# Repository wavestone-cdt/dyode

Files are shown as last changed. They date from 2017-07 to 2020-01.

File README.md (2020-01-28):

# DYODE : Do Your Own Diode

A DIY, low-cost data diode for ICS
This project aims at creating a working data diode for a fraction of the price of the commercial ones.

This project includes two versions of DYODE :
* DYODE full : a 19" rack-sized data diode

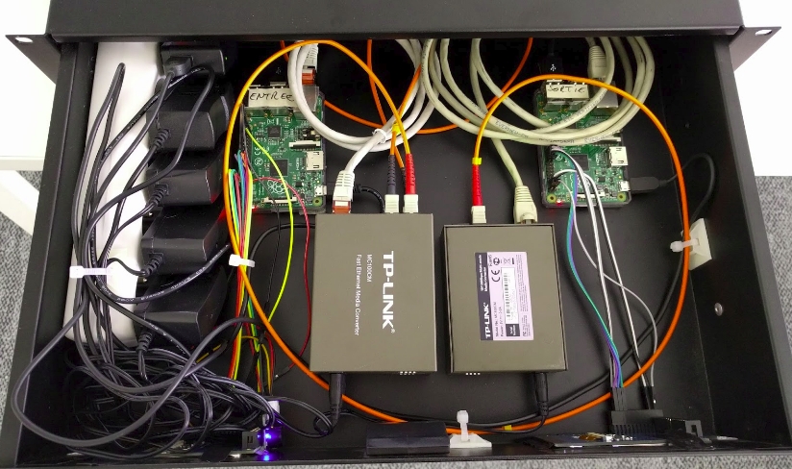
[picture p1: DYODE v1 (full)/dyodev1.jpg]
dyodev1 picture

* DYODE light : a very compact and ultra low-cost version with performance limitations

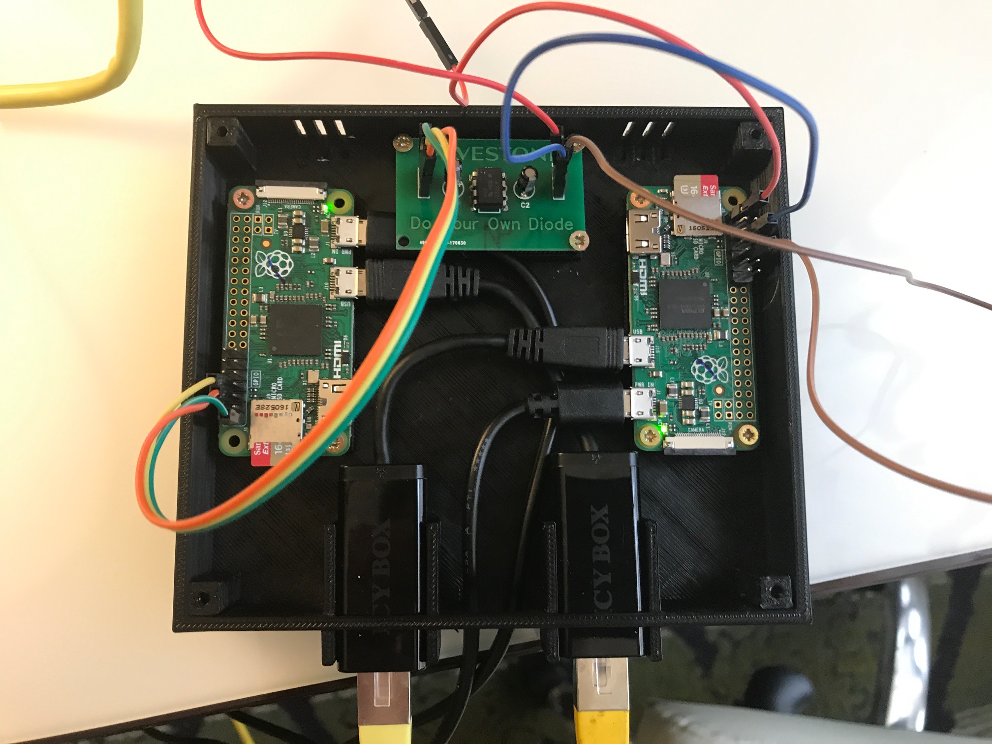
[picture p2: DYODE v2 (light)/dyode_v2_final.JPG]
dyodev2 picture


For detailed information, including steps to make your own, take a look at the [wiki](https://github.com/wavestone-cdt/dyode/wiki).
You may also take a look at the [public talks](https://github.com/wavestone-cdt/dyode/tree/master/Talks) done on this project.

## Hardware
The DYODE project is composed of 3 main parts:
* An INPUT counter
* A unidirectional, light-based data transfer mechanism
* An OUTPUT counter

The full version relies on optical-copper converters to transmit data, while the light version uses an optocoupler.

Hardware for DYODE light is open-source: PCB Gerber files are provided, as well as `.stl` files to 3D print the case.

## Software
DYODE is an open-source project developed in Python.

Features
* Modbus data transfer
* File transfer (*DYODE full only*)
* Screen sharing (*DYODE full only*)

## License
This project is published under GPLv3.
Take a look at [the full license](LICENSE).

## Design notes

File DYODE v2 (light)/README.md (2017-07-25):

# DYODE : Do Your Own Diode

A DIY, low-cost data diode for ICS

dyodev2 picture

This project aims at creating a working data diode for a fraction of the price of the commercial ones.

This is the newest version, using an optocoupler to transmit information.

Please take a look at the [wiki](https://github.com/wavestone-cdt/dyode/wiki) for all information.

## License
This project is published under GPLv3.
Take a look at [the full license](LICENSE).

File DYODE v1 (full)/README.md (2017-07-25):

# DYODE : Do Your Own DyodE
A low-cost (~200 €) data diode aimed at Industrial Control Systems.

## Hardware
We use very standard hardware:
* 3 Copper-Optical converters
* 2 Raspberry Pis
* A few additional components, such as USB-Ethernet NICs, RJ45 cables, ...

## Software
We use ``udpcast`` to transfer files over a unidirectional channel. Modbsu and screen sharing work over a very simple Python UDP socket implementation.

## Features
At the moment, DYODE can be used for the following usages:
* File transfer
* Modbus data transfer
* Screen sharing

You can take a look at the video to learn more about the usage, and ``INSTALL.md`` for installation guidelines.

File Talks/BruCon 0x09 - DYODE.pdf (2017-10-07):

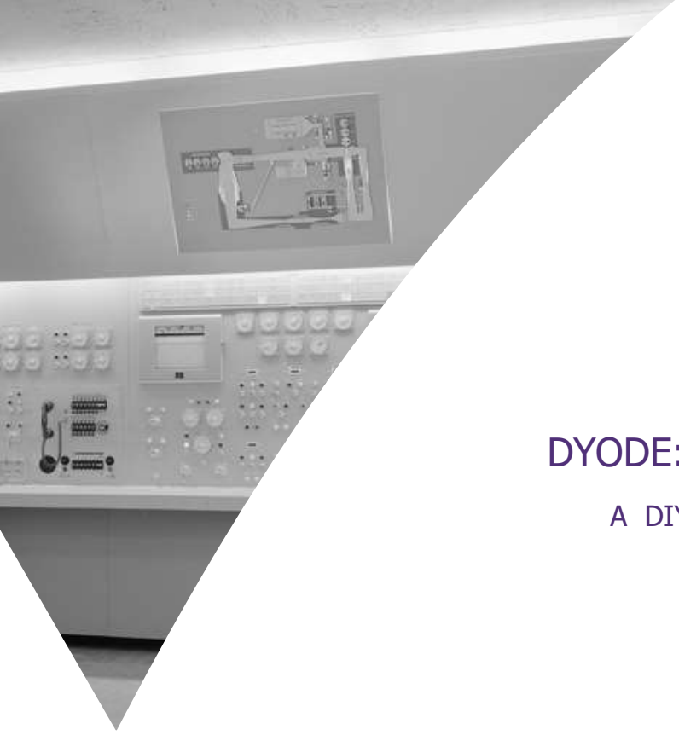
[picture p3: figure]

# DYODE: Do Your Own DiodE

### A DIY, low-cost data diode for ICS

BruCon, October 2017
Arnaud Soullié

UNPROTECTED // PUBLIC CONFERENCE | 2

### Who are we?

DYODE: DO YOUR OWN DIODE

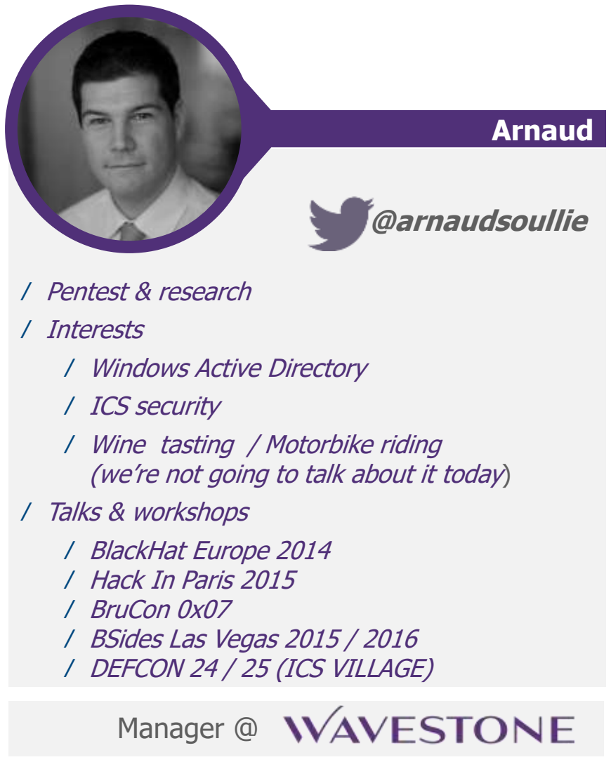
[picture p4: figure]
Manager @; ⁄ Pentest & research; ⁄ Interests; ⁄ Windows Active Directory; ⁄ ICS security; ⁄ Wine tasting / Motorbike riding; ⁄ Talks & workshops; ⁄ BlackHat Europe 2014 ⁄ Hack In Paris 2015 ⁄ BruCon 0x07 ⁄ BSides Las Vegas 2015 / 2016 ⁄ DEFCON 24 / 25 (ICS VILLAGE); Arnaud; @arnaudsoullie

(we’re not going to talk about it today)

⁄ Advisory & audit (used to do pentests) ⁄ Interests
⁄ Windows Security
⁄ Cryptophony

⁄ Talks: IEEE ICC 2009, JSSI 2013 and 2014, SSTIC 2016, Bsides Las Vegas 2016

⁄ Book Information Security, Eyrolles Edition [in French] – written with several authors including Arnaud

Ary

Tax exile @ $Big4 in Switzerland ;)

### ICS 101

### DATA DIODES 101

## / AKA “one-way gateway”

## / Use of light as the transport medium

## / PN junction prevents electrons from going backwards

→ Security property is backed by physics. Hack that.

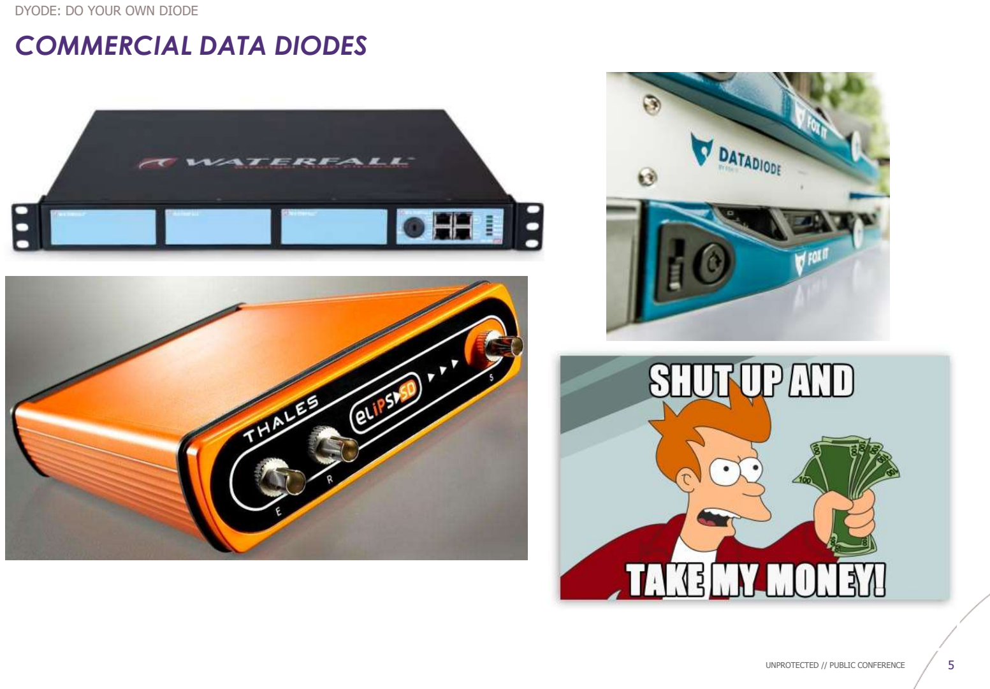
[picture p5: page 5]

### COMMERCIAL DATA DIODES

### WHY THIS PROJECT ?

### / Feedback from lots of ICS security assignments

### → There are lots of needs for exchanging information between CORP and ICS

### / Commercial data diodes exist, but are quite expensive

### → Security / cost trade-off , not easy to sell

### / Examples

### Predictive maintenance : send a 100kb file every 6 hours to a 3rd party Cooling units : 3rd party needs to access a PLCs output in real-time for efficiency improvement

### → Data only needs to be exchanged one-way, but in these examples the high cost of a commercial Data Diode combined with business needs to exchange information, resulted in uncontrolled network connection between two networks

### DYODE PROJECT

### / Based on existing work : Lagadec, Austin Scott, Robert Gabriel

### / Low cost & DIY

### Use of standard hardware (COTS) and open-source software

### Target cost of 200$ per unit

### / Objectives

### Proof of Concept

### Transparent, easy to deploy solution

### Share the results

### DYODE project has no commercial intent, but an implementation by a vendor is authorized

### / Use of copper-optical converters

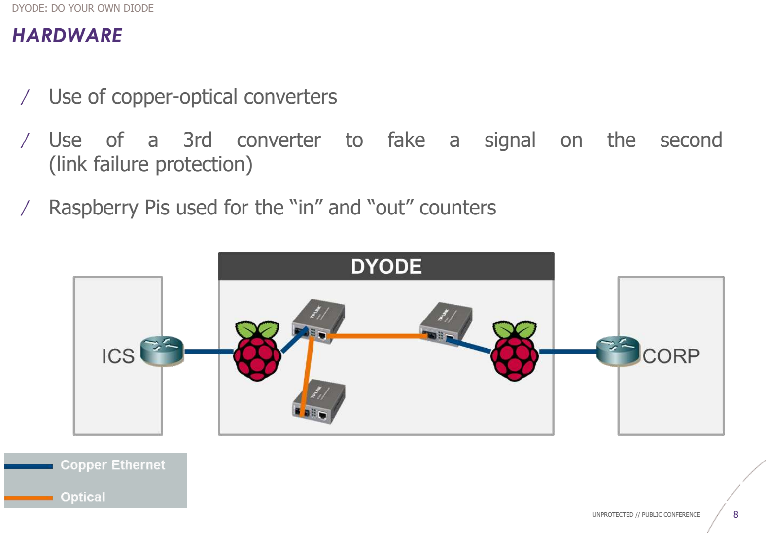
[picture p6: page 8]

### HARDWARE

/ Use | of | a | 3rd | converter | to | fake | a | signal | on | the | second

### (link failure protection)

### / Raspberry Pis used for the “in” and “out” counters

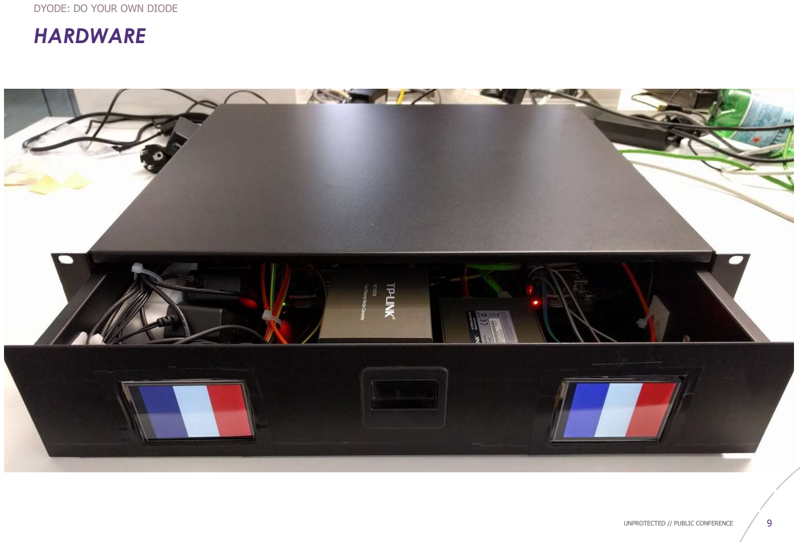
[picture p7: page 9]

### HARDWARE

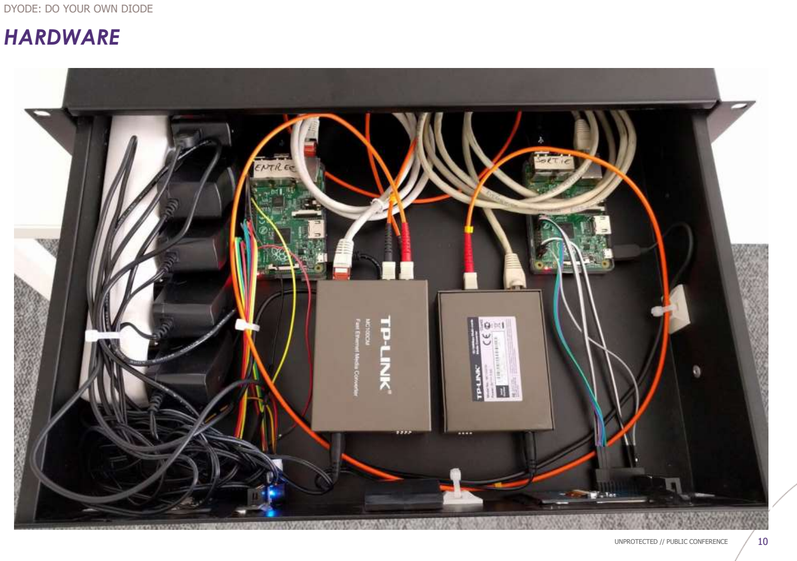
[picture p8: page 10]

### HARDWARE

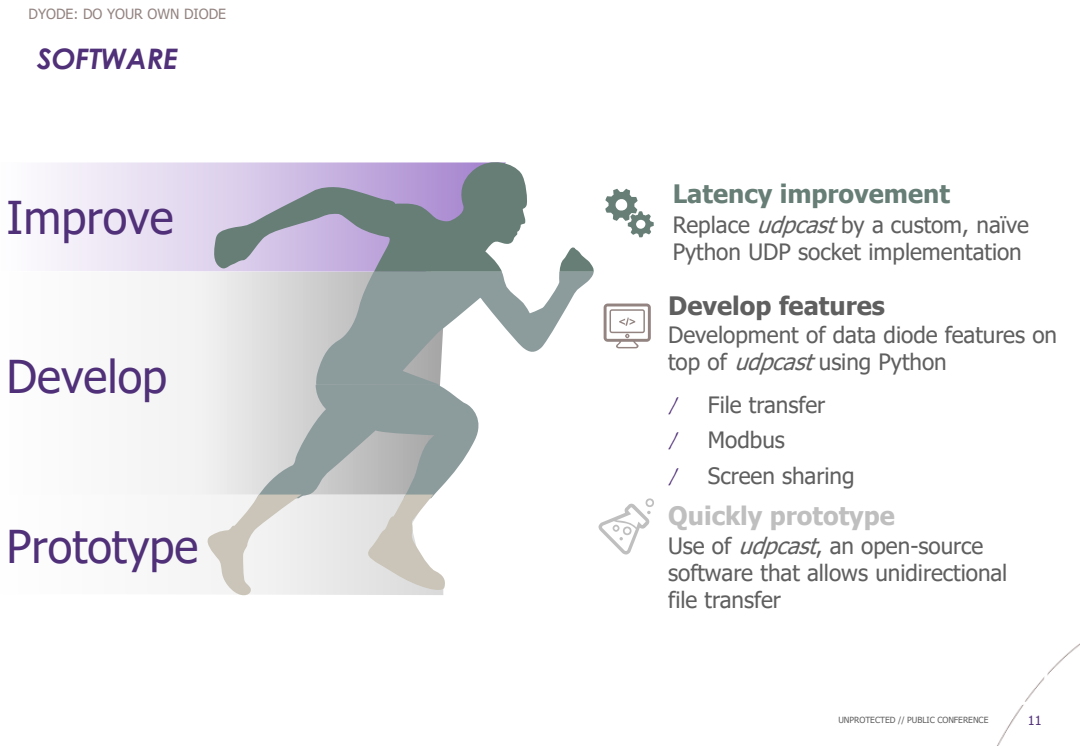
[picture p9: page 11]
SOFTWARE; Prototype; Develop; Improve

Latency improvement
Replace udpcast by a custom, naïve
Python UDP socket implementation

Develop features
Development of data diode features on
top of udpcast using Python
/ File transfer
/ Modbus
/ Screen sharing
Quickly prototype
Use of udpcast, an open-source
software that allows unidirectional
file transfer

### DEMO

# [VIDEO] DEMO TIME!

### DEMO

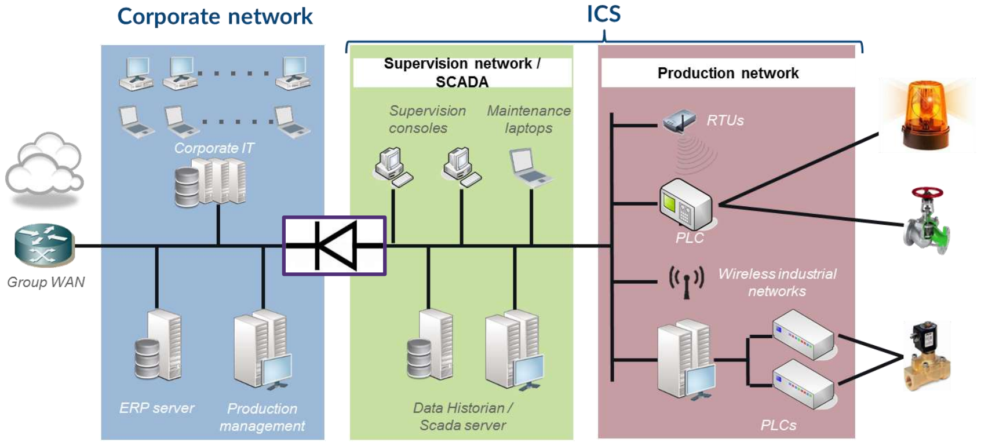
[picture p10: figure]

### DEMO

### FILE TRANSFER WORKFLOW

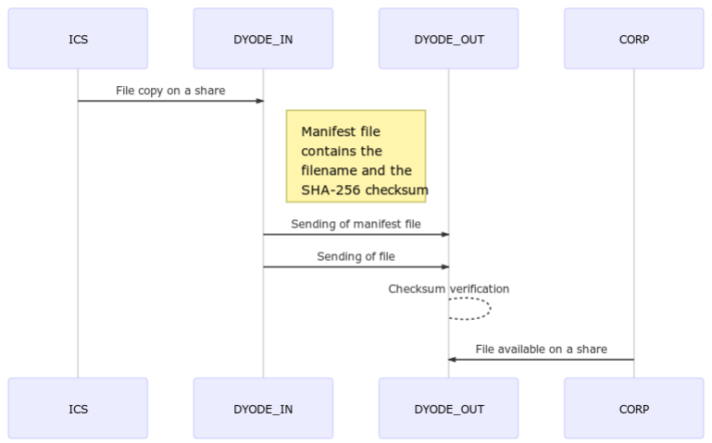
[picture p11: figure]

### MODBUS TRANSFER WORKFLOW

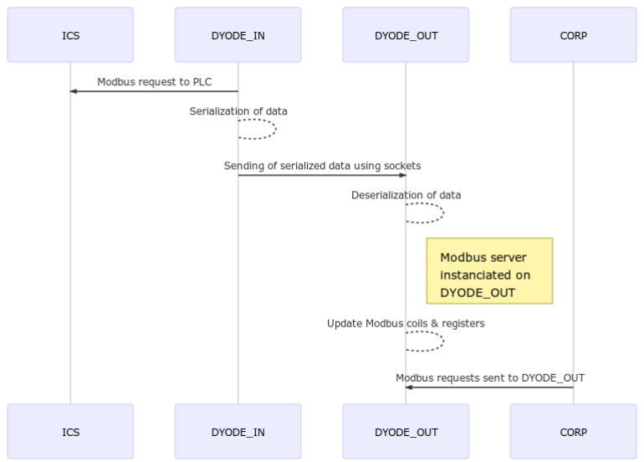
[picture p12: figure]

### SCREEN SHARING WORKFLOW

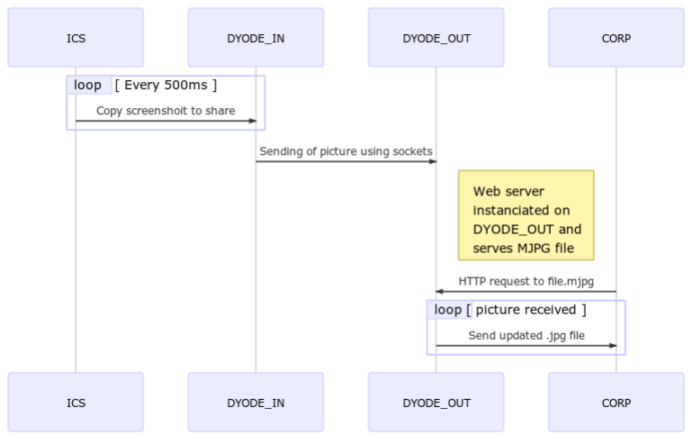
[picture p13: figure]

config_name: "Dyode test"
config_version : 1.0
config_date: 2016-05-04

dyode_in:
ip: 10.0.1.1
mac: b8:27:eb:89:1e:f3
dyode_out:
ip: 10.0.1.2
mac: b8:27:eb:b1:ff:ab

modules:
"File share 1":
type: folder
port: 9600
in: /home/pi/in
out: /home/pi/out

"Modbus PLC":
type: Modbus
port: 9400
ip: 192.168.1.150
port_out: 502
registers:
- 0-100
- 400-450
coils:
- 0-10
- 100-110
"Screen_share_1":
type: screen
port: 9900
in: /home/pi/screenz
out: /home/pi/screenz

### CONFIGURATION FILE

### REAL COST

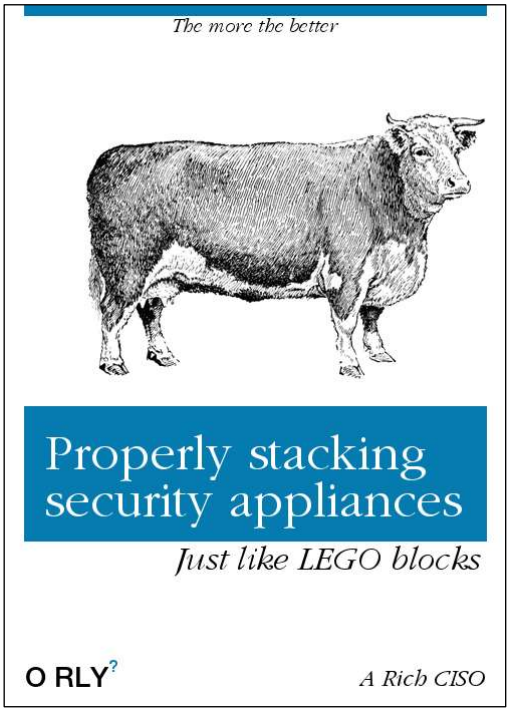
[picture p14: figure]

Component | Quantity | Cost
Raspberry Pi + power supply | 2 | 92€
Copper-Optical converter | 3 | 117€
Optical cable | 2 | 15€
USB-Ethernet adapter | 4 | 16€
Rack 19” 2U | 1 | 59€
Screens | 2 | 70€
Buzzer | 1 | 5€
GRAND TOTAL | | 374€

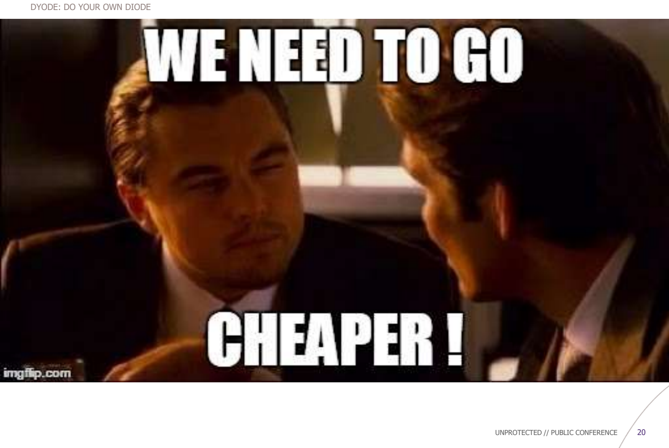
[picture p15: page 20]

### WHY NOT JUST CUT THE CABLE?

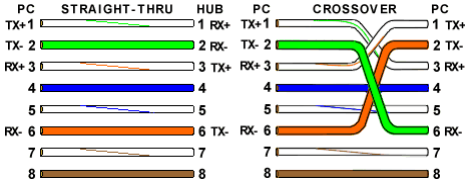
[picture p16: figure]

/ Yes, it is possible to have a one-way gateway by using half-duplex mode on network interfaces and cutting the 2 RX of the Ethernet cable

/ Seems simpler than the DYODE implementation

### Cutting the cable?

/ You’ll still need the “in” and “out” counters (Raspi) to use a one-way connection for TCP

protocols

/ In theory, advanced attacks may allow to send information the other way around, for

example by switching ports “up” and “down”

### However

### IMPROVEMENTS > Reducing the cost

## Replace the Ethernet-FO converters by a serial connection with an optocoupler also called photocoupler

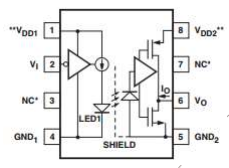
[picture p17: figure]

/ Diode opto-isolator = LED + photodiode
/ Very low cost solution (2€)
/ Acceptable bandwidth for some usages (20ko/s) / For very sensitive environments, do your own

(it is harder to backdoor a LED than a black box circuit in epoxy)

## Most expensive components : in/out counters & optical converters → Let’s change that !

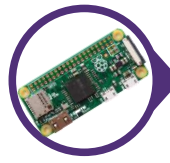
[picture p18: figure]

## Replace classical RSPi by RSPi 0 (5$) (When you can find one…)

### DYODE Ultra-low cost version

Component | Quantity | Cost
Raspberry Pi 0 + power supply + SD Card | 2 | 32€
Optocoupler+capacitor+misc. | 1 | 5€
MicroUSB-Ethernet adapter | 2 | 30€
DIN Rail compatible box | 1 | 12€
GRAND TOTAL | | 80€

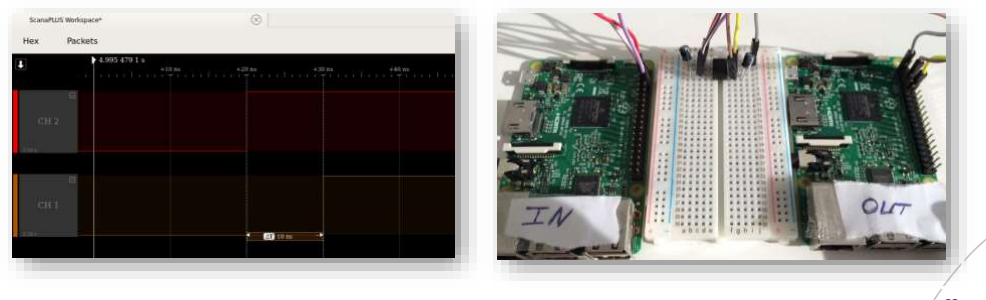
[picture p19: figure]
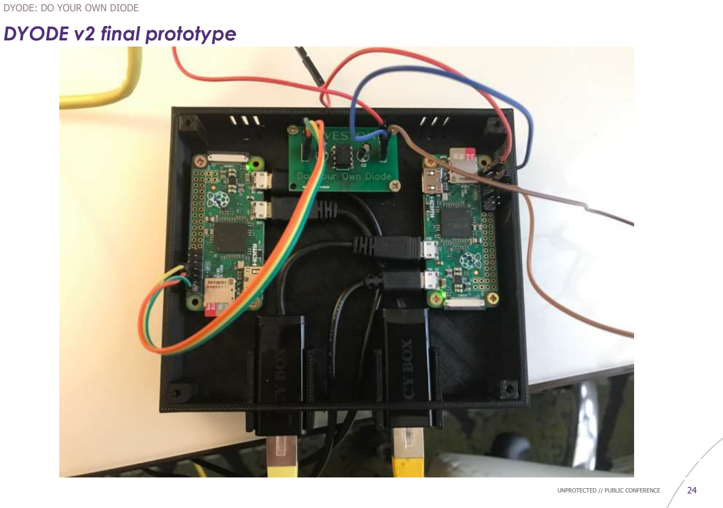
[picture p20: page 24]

### DYODE v2 final prototype

### Hardware is open source as well !

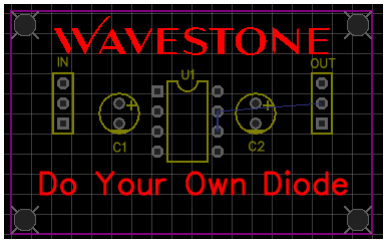
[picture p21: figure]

*PADS-PCB*
*PART*
U1 DIP--8
IN HDR-3X1/2.54
[…]
C2 CAP-D5.0XF2.0

*NET*
*SIGNAL* U1_2
IN.2 U1.2
[…]
*END*

Netlist

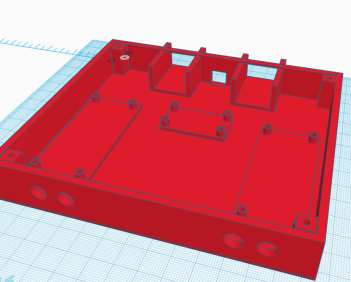
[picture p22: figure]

solid stl_item0 | facet
normal 0 0 1 | outer loop
vertex -56.25 23.799 9
vertex -56.5 24.232 9
vertex -56.561 23.561 9
endloop | endfacet | facet
normal 0 0 1 | outer loop
vertex -55.112 21.051 9
vertex -54.982 20.568 9
[…]

STL file for 3D-printing the case

### DEMO

# [LIVE] DEMO TIME!

### DEMO

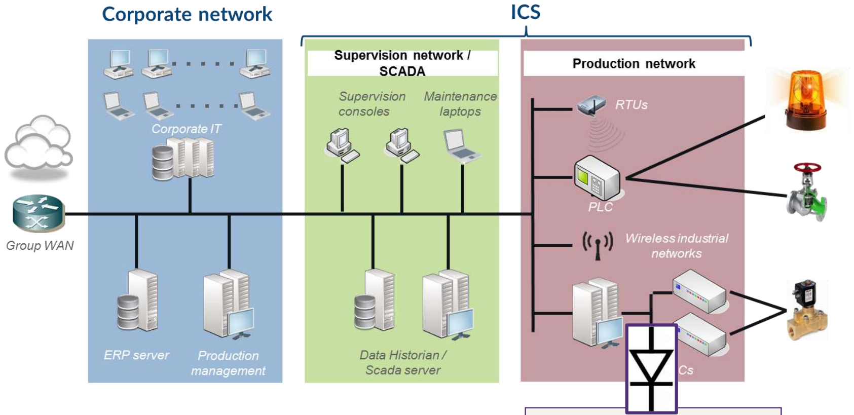
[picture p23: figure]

Untrusted 3rd party
($ICS_VENDOR ?)

ICS | CORPORATE

### SO, IS IT MAGICAL ?

/ Nope.

### / Most of the time, need to exchange data two ways:

### / CORP -> ICS for updates, docs

### / ICS -> CORP to export production data

/ So you’ll end up with two data diodes, one in each direction, which goes a bit against the principle...

### THREAT MODELING (SIMPLIFIED)

No data will go from OUT to IN. That’s all. Period.

### What does DYODE guarantees?

The overall security of the solution still relies on logical hardening.

If the “out” corner is not secured, it might be possible for an attacker to

/ Perform a Denial of Service

/ Compromise the Raspi and modify the data

### What attacks are still possible?

### LIMITS

Not compatible with safety-critical environments (yet)

/ Low speed, a few mbs

/ High latency caused by flat file transfer

→ Replaced by a naive, native Python sockets implementation

Performances

/ Side channels, especially based on electromagnetic leaks (TEMPEST) were not taken in consideration in the threat model

/ However, | EM | leaks | can | be | reduced | with | faraday | cages
→ Re-use of forensics (relatively low cost) portable faraday cages used when handling phones?

Side channels

/ In and out gateways are not especially hardened and can be compromised

/ The target it only to prevent information flowing from ICS to CORP

Gateway hardening

### Roadmap

- Acting as an application firewall in whitelist mode to check the correctness of the parameters

Modbus/S7 integrity control

- Ex: Using a cronjob + a SNMP trap on
the receiver side
Link status monitoring - Heartbeat | ▪ | Level1: generate hash of the files/values transferred
- Level2: use 2 DYODE and 3 RSPi (in,
| | out and crypto-signer); the RSPi in the middle combined with an OpenPGP card can generate the hashes and add a signature

Traceability of the transfers

- Level1: perform a file validation by the receiving gateway, either with an AV (basic) or a specific parser/converter such as Lagadec’s Exefilter or CIRCLean or against specific hashes for binaries
- Level2: use a dedicated device for file parsing which can be further hardened (the exposition can be limited to the parsing component, the TCP/IP stack and a limited number or entry points)
- Level3: Use Qubes OS throwable VM

File integrity checking (1/2)

- Add support for SNMP, Syslog, CIFS, SMTP, FTP, SFTP, etc

Other protocols

### Current deployments

### / Similar setup, different implementation (.NET) made by one of our clients

/ Used | in | a | summer | internship | for | Virginia | Space

### ohmygawddyodeintospace https://github.com/EBUJOLD/data-diode

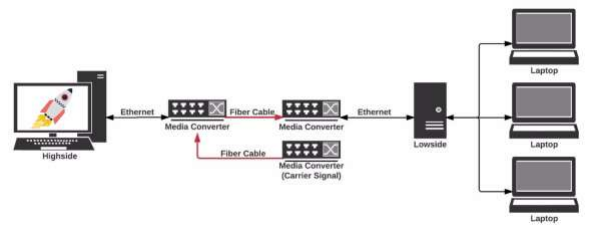
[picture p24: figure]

### / Tests in progress at another client to isolate safety PLCs from the DCS

## Conclusion

## https://github.com/wavestone-cdt/dyode

It works. | It’s cheap. | Contribute !

As demonstrated
[if the demo did not fail] DYODE answers to safe
data exchange needs

300€ for the v1
80€ for the v2

We need contributions to
make the product more
reliable and add features

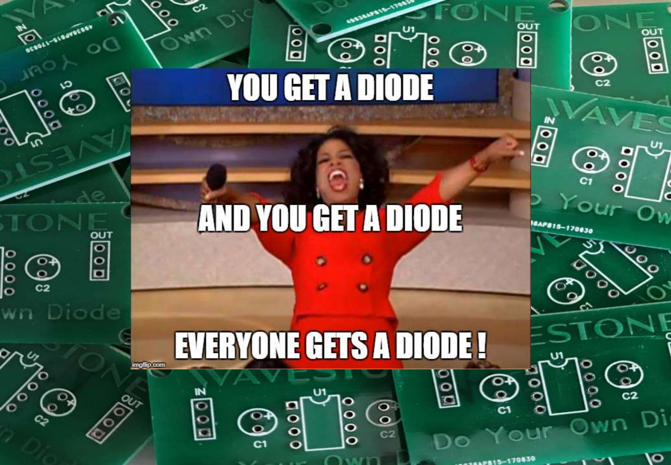
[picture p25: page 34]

wavestone-advisors.com
@wavestone_

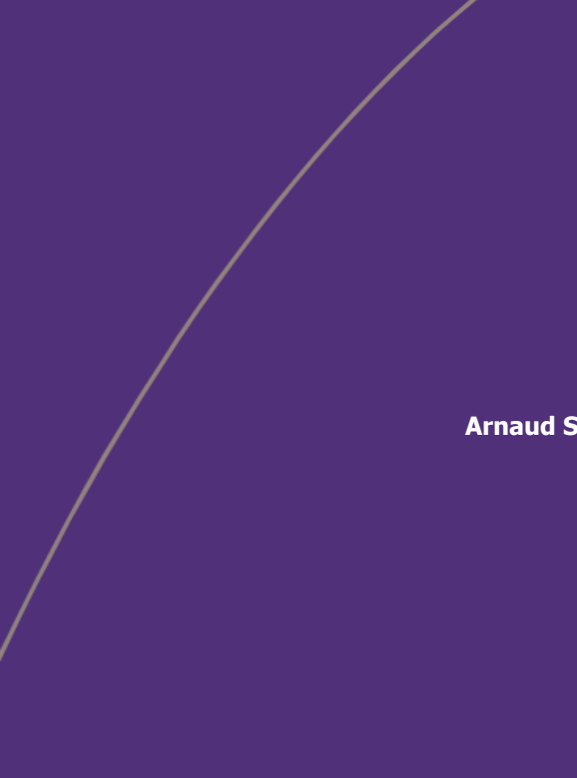
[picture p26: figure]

Arnaud SOULLIE | Arnaud.SOULLIE@wavestone.com

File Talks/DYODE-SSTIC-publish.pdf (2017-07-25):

# DYODE


# Do Your Own DyodE

## Une diode réseau à bas coût pour les réseaux industriels

1

Arnaud Soullié, Solucom
Ary Kokos

# PRINCIPES DE LA DIODE RESEAU

- Passerelle unidirectionnelle

- Utilisation d’une liaison optique pour la transmission

- La jonction PN empêche les électrons de circuler dans le sens
inverse

⇒ La propriété de sécurité est assurée physiquement. Hack that.

# POURQUOI CE PROJET ?


3

Retour d’expérience de missions SI industriel
⇒ Nombreux besoins d’échange de données

Les diodes réseau existantes sont performantes, mais chères
⇒ Le rapport gain en sécurité vs prix n’est pas évident

Deux exemples :
- Envoi de données d’usure des pièces : 100ko à envoyer toutes les 6h au prestataire en charge du MCO
- Système frigorifique : le prestataire exige une copie des données d’un automate en temps quasi-réel

⇒ Ces deux besoins d’échange de données résultent en une connexion avec un SI tiers

# LE PROJET DYODE


Basé sur des travaux existants : Lagadec, Austin Scott, Robert
Gabriel

Utilisation de matériel standard et développement d’un logiciel libre
Coût cible de 200€ par diode

Objectifs
- Prouver la faisabilité
- Créer une solution simple à mettre en place, transparente
- Partager nos résultats

Note: le projet DYODE n'a aucune visée commerciale, mais une
implémentation et une maintenance par un éditeur/constructeur est
autorisée

# LE MATERIEL


- Utilisation de convertisseurs Cuivre-Optique pour assurer l’ unidirectionnalité en ne branchant qu’un câble TX -> RX
- Utilisation d’un 3ème convertisseur pour “tromper” l’émetteur (link failure protection)
- Utilisation de Raspberry Pi pour les guichets d’entrée et de sortie

5

# LE MATERIEL


- Utilisation de convertisseurs Cuivre-Optique pour assurer l’ unidirectionnalité en ne branchant qu’un câble TX -> RX
- Utilisation d’un 3ème convertisseur pour “tromper” l’émetteur (link failure protection)
- Utilisation de Raspberry Pi pour les guichets d’entrée et de sortie

6

# LE LOGICIEL


Volonté d’avoir une solution fonctionnelle rapidement

Utilisation du logiciel open-source “udpcast” pour le transfert de fichier plat via la diode

Construction de fonctions autour de cet outil via un développement en Python

### 3 fonctions supportées aujourd’hui

- Transfert de fichier plat
- Transfert de données Modbus
- Partage d’écran sans interaction (télémaintenance, etc)

Code source : ~500 lignes utiles

7

# LIMITES ACTUELLES


8

- Vitesse de transfert faible, quelques Mo/s
- Latence élevée du fait de l’utilisation de fichiers plats
⇒ Remplacé récemment par une implémentation directe via sockets UDP pour Modbus et partage d’écran
- Solution non-adaptée pour des usages critiques (composants standards non-durcis, pas de haute disponibilité)

# ROADMAP

# Prochaines étapes


9

- Durcissement sécurité
- Fiabilisation (mise en place d’un heartbeat)

# Améliorations possibles

- Ajout de connecteurs
- S7 (automates Siemens)
- SYSLOG
- SMTP
- …
- Contrôle d’intégrité / d’inocuité des données transmises
- Signature des fichiers échangés
- Création d’une version very low cost basée sur Raspberry Pi Zero et liaison infrarouge

# Des questions ?


@arnaudsoullie
arnaud.soullie@solucom.fr

https://github.com/arnaudsoullie/dyode

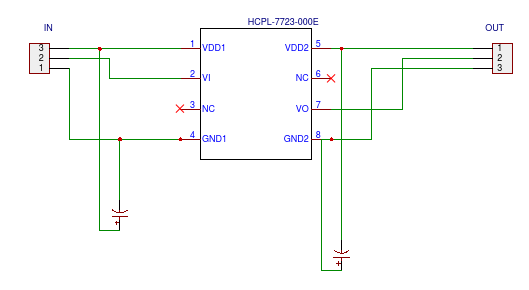
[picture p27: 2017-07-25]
DYODE v2 (light)/dyode_diagram.png

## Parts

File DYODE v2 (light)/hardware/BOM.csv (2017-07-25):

id | value | quantity | package | components | LCSC | Manufacturer | Manufacturer Part | Supplier
1 | HCPL-7723-000E | 1 | DIP--8 | U1
2 | Header-Male-2.54_1x3 | 2 | HDR-3X1/2.54 | IN,OUT
3 | 0.1UF | 2 | CAP-D5.0XF2.0 | C1,C2

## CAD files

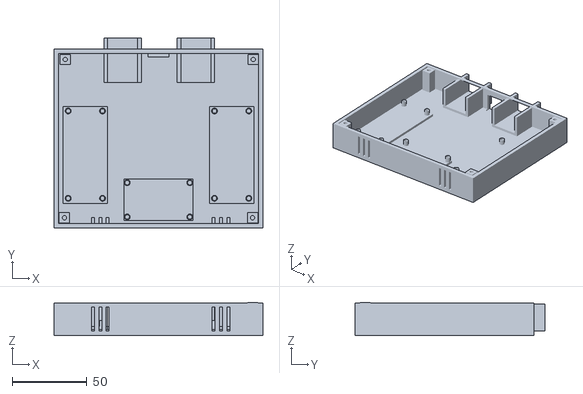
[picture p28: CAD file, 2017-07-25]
DYODE v2 (light)/hardware/DYODE-Pi0-case bottomv1.stl
140.0 x 127.5 x 22.2

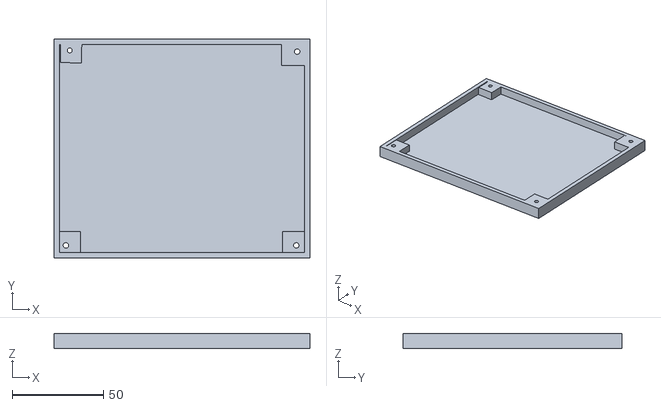
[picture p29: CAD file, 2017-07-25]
DYODE v2 (light)/hardware/DYODE-Pi0-case topv1.stl
140.0 x 120.0 x 8.00

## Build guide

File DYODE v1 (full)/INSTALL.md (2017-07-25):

# Install notes for DYODE

## Hardware setup
DYODE is composed of two hardware types:
* 2 x  Computers (for example Raspberry Pis)
* 3 x Copper/Optical converters (TP-LINK MC100CM for example)
* Additional NICs (3 per computer are needed)
* 2 optical cables
* Some RJ-45 cables

## Software setup
DYODE is developed in Python and heavily relies on open-source libraries.

First of all, you'll need to install [udpcast](https://www.udpcast.linux.lu/), which is the tool used to transfer files through the diode.

Then, you'll require Python 2 and the following modules:
* pymodbus
* pyinotify
* YAML
* asyncore

### Configuration file
Configuration is based on a YAML file, which must be copied to both input and output diodes.

Below is an example of such a configuration file
```yaml
config_name: "Dyode test"
config_version : 1.0
config_date: 2016-05-04

dyode_in:
  ip: 10.0.1.1
  mac: b8:27:eb:89:1e:f3
dyode_out:
  ip: 10.0.1.2
  mac: b8:27:eb:b1:ff:ab

modules:
  "Partage de fichier 1":
     type: folder
     port: 9600
     in: /home/pi/in
     out: /home/pi/out
  "Partage 2":
     type: folder
     port: 9700
     in: /home/pi/in2
     out: /home/pi/out2
  "Automate Modbus 1":
     type: Modbus
     port: 9400
     ip: 192.168.1.150
     port_out: 502
     registers:
       - 0-100
       - 400-450
     coils:
       - 0-10
       - 100-110
  "Automate Modbus 2":
    type: modbus
    port: 9500
    ip: 127.0.0.1
    port_out: 503
    registers:
      - 0-10
      - 400-402
    coils:
      - 0-10
      - 100-110
  "Partage d'ecran presta":
     type: screen
     port: 9900
     in: /home/pi/screenz
     out: /home/pi/screenz
```
It's supposed to be straight-forward.
Each entry is defined by its type (folder, Modbus or screen), and some properties:
* port is the base port that will be used by udpcast to send the data
* in is the path of the folder on the input diode where the files to be transfered are located
* out is the path on the output diode where the received files will be stored
* for modbus, you need to specify the coils and registers range that you want to transfer

Copy all files in the two computers. To launch the diode, launch :
* dyode_in.py on the input computer
* dyode_out.py on the output computer

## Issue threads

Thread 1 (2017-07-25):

Case too small

arnaudsoullie, 2017-07-25:
The case for DYODE v2 needs to be a bit taller.

The Dupont wires prevent the case from being correctly closed.

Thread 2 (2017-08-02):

Can't establish connection with v1

nickcounts, 2017-08-02:
Any assistance you can provide with media converter configuration? We can't seem to get the hardware layer to work.

Can you provide more information regarding what DIP switch settings you used for the media converters and what indicator lights should be illuminated?

nickcounts, 2017-08-02:
We are trying to follow your guide. Spoofing the carrier signal appears to be the issue. Here are some photos of our setup:

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

nickcounts, 2017-08-03:
I believe we had a combination of hardware and software layer issues.

We will post our working switch configuration. Once we started seeing ARP queries (used wireshark on the receiver) we knew we had the hardware working.

arnaudsoullie, 2017-08-03:
Hi Nick,
From your last update I get that data is flowing from IN to OUT ?
Let me know if you encounter any software issue.
In the picture you posted, it seems that the 3rd converter is connected by its RX to the TX of the OUT converter. Shouldn't it be connected to the RX of the IN converter ?

EBUJOLD, 2017-08-08:
Our problem was two parts:
1. Our machines forgot their ARP addresses upon reboot
2. We didn't have our DIP switches configured correctly.

I have documented how we got our data diode to work (using DYODE software) on my repo:

[https://github.com/EBUJOLD/data-diode](https://github.com/EBUJOLD/data-diode)

Thank you for your time.

Closed 2017-09-12.

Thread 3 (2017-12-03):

DYODE V1 dyode_out.py

pooryasheikh, 2017-12-03:
hi, at first thank for this app.
i have problem to run dyode_out.py:
[root@CentOSOUT DYODE v1 (full)]# sudo python dyode_out.py
INFO:root:Loading config file
INFO:root:Configuration name : Dyode test
INFO:root:Configuration version : 1.0
INFO:root:Configuration date : 2016-05-04
INFO:root:Dyode input ip : 192.168.1.100 (08:00:27:9e:5d:fb)
INFO:root:Dyode output ip : 192.168.1.150 (08:00:27:9e:5d:fb)
DEBUG:root:Parsing "Partage de fichier 1"
DEBUG:root:Trying to launch a new process for module "Partage de fichier 1"
DEBUG:root:Instanciating a file transfer module :: Partage de fichier 1
DEBUG:root:Waiting for file ...
DEBUG:root:2017-12-03 16:30:17.712871
DEBUG:root:{'in': '/home/pi/in', 'type': 'folder', 'port': 9600, 'out': '/home/pi/out'}
DEBUG:root:9600
DEBUG:root:udp-receiver --nosync --mcast-rdv-addr 10.0.1.1 --interface eth1 --portbase 9600 -f 'manifest_Partage de fichier 1.cfg'
Process Partage de fichier 1:
Traceback (most recent call last):
  File "/usr/lib64/python2.7/multiprocessing/process.py", line 258, in _bootstrap
    self.run()
  File "/usr/lib64/python2.7/multiprocessing/process.py", line 114, in run
    self._target(*self._args, **self._kwargs)
  File "dyode_out.py", line 28, in launch_agents
    dyode.file_reception_loop(properties)
  File "/root/dyode/DYODE v1 (full)/dyode.py", line 44, in file_reception_loop
    wait_for_file(params)
  File "/root/dyode/DYODE v1 (full)/dyode.py", line 69, in wait_for_file
    files = parse_manifest(manifest_filename)
  File "/root/dyode/DYODE v1 (full)/dyode.py", line 36, in parse_manifest
    for item, value in parser.items('Files'):
  File "/usr/lib64/python2.7/ConfigParser.py", line 642, in items
    raise NoSectionError(section)

how can i solve it?

arnaudsoullie, 2017-12-04:
Hello !

Is it possible to post logs from the input diode from the same time ?

Can you poste the content of ``manifest_Partage de fichier 1.cfg`` ?

Does this happen for the first file or after a certain period of time ?

pooryasheikh, 2017-12-04:
hello, thanks for reply.
i just compile the input dyode without any problem after that i go to output dyode and try to compile, but get errors
I don’t have "manifest_Partage de fichier 1.cfg” file in my Dyode folder.

Dyode OUT:
[root@CentOSOUT DYODE v1 (full)]# python dyode_out.py
INFO:root:Loading config file
INFO:root:Configuration name : Dyode test
INFO:root:Configuration version : 1.0
INFO:root:Configuration date : 2016-05-04
INFO:root:Dyode input ip : 192.168.1.100 (08:00:27:9e:5d:fb)
INFO:root:Dyode output ip : 192.168.1.150 (08:00:27:9e:5d:fb)
DEBUG:root:Parsing "Partage de fichier 1"
DEBUG:root:Trying to launch a new process for module "Partage de fichier 1"
DEBUG:root:Instanciating a file transfer module :: Partage de fichier 1
DEBUG:root:Waiting for file ...
DEBUG:root:2017-12-03 17:48:17.820088
DEBUG:root:{'in': '/home/pi/in', 'type': 'folder', 'port': 9600, 'out': '/home/pi/out'}
DEBUG:root:9600
DEBUG:root:udp-receiver --nosync --mcast-rdv-addr 10.0.1.1 --interface eth1 --portbase 9600 -f 'manifest_Partage de fichier 1.cfg'
Process Partage de fichier 1:
Traceback (most recent call last):
  File "/usr/lib64/python2.7/multiprocessing/process.py", line 258, in _bootstrap
    self.run()
  File "/usr/lib64/python2.7/multiprocessing/process.py", line 114, in run
    self._target(*self._args, **self._kwargs)
  File "dyode_out.py", line 28, in launch_agents
    dyode.file_reception_loop(properties)
  File "/root/dyode/DYODE v1 (full)/dyode.py", line 44, in file_reception_loop
    wait_for_file(params)
  File "/root/dyode/DYODE v1 (full)/dyode.py", line 69, in wait_for_file
    files = parse_manifest(manifest_filename)
  File "/root/dyode/DYODE v1 (full)/dyode.py", line 36, in parse_manifest
    for item, value in parser.items('Files'):
  File "/usr/lib64/python2.7/ConfigParser.py", line 642, in items
    raise NoSectionError(section)
NoSectionError: No section: ‘Files'

DYODE IN:
[root@CentOSIN DYODE v1 (full)]# sudo python ./dyode_in.py
INFO:root:Loading config file
INFO:root:Configuration name : Dyode test
INFO:root:Configuration version : 1.0
INFO:root:Configuration date : 2016-05-04
INFO:root:Dyode input ip : 192.168.1.100 (08:00:27:9e:5d:fb)
INFO:root:Dyode output ip : 192.168.1.150 (08:00:27:9e:5d:fb)
DEBUG:root:Number of modules : 1
DEBUG:root:Max bitrate per module : 8.0 mbps
DEBUG:root:Parsing Partage de fichier 1
DEBUG:root:Trying to launch a new process for module Partage de fichier 1
DEBUG:root:Partage de fichier 1
DEBUG:root:{'bitrate': 8.0, 'in': '/home/pi/in', 'type': 'folder', 'port': 9600, 'out': '/home/pi/out'}
DEBUG:root:Instanciating a file transfer module :: Partage de fichier 1
DEBUG:root:Function "folder" launched with params {'bitrate': 8.0, 'in': '/home/pi/in', 'type': 'folder', 'port': 9600, 'out': '/home/pi/out'}:
DEBUG:root:watching :: /home/pi/in

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

pooryasheikh, 2017-12-04:
problem solved. i didnt change those lines.
Thanks for everythings.
In dyode.py on both machines, make the following changes:

On line 55: We changed the IP address to our highside address
On line 55: We changed eth1 to our highside ethernet adapter ID (eth3)
On line 107: We changed the IP addresses to our lowside IP address
On line 109: We changed eth1 to our lowside ethernet adapter ID (eth0)

Closed 2017-12-04.

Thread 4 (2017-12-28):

conection error 111

raspifuzzy, 2017-12-28:
Thanks for share your project.
I  built the v2 version using RaspPi3 and followed your steps but receive following error on Input Raspberry.
IP is the Input Raspberry

INFO:root:Loading config file
INFO:root:Configuration name : Dyode v2
INFO:root:Configuration version : 1.0
INFO:root:Configuration date : 2017-07-25
DEBUG:root:Parsing Automate Modbus 1
DEBUG:root:Trying to launch a new process for module Automate Modbus 1
DEBUG:root:Automate Modbus 1
DEBUG:root:{'coils': ['0-1'], 'registers': ['0-105'], 'port_out': 502, 'ip': '192.168.78.50', 'type': 'modbus', 'port': 9400}
DEBUG:root:Modbus agent : Automate Modbus 1
DEBUG:root:Modbus Loop
Performing an action which may throw an exception.
ERROR:pymodbus.client.sync:Connection to (192.168.78.50, 502) failed: [Errno 111] Connection refused
DEBUG:root:['0-105']
DEBUG:root:['0-1']
DEBUG:root:Register start number : 0
DEBUG:root:Register end number : 105
DEBUG:root:Number of registers to read : 105
ERROR:pymodbus.client.sync:Connection to (192.168.78.50, 502) failed: [Errno 111] Connection refused
DEBUG:root:Error connecting to 192.168.78.50
DEBUG:root:Modbus Error: [Connection] Failed to connect[192.168.78.50:502]
DEBUG:root:Data size : 25
^CError in atexit._run_exitfuncs:
Traceback (most recent call last):
  File "/usr/lib/python2.7/atexit.py", line 24, in _run_exitfuncs
    func(*targs, **kargs)
Process Automate Modbus 1:
  File "/usr/lib/python2.7/multiprocessing/util.py", line 325, in _exit_function
Traceback (most recent call last):
  File "/usr/lib/python2.7/multiprocessing/process.py", line 258, in _bootstrap
    p.join()
  File "/usr/lib/python2.7/multiprocessing/process.py", line 145, in join
    res = self._popen.wait(timeout)
  File "/usr/lib/python2.7/multiprocessing/forking.py", line 154, in wait
    self.run()
  File "/usr/lib/python2.7/multiprocessing/process.py", line 114, in run
    self._target(*self._args, **self._kwargs)
  File "dyode_in.py", line 24, in launch_agents
    return self.poll(0)
  File "/usr/lib/python2.7/multiprocessing/forking.py", line 135, in poll
    modbus.modbus_loop(module, properties)
    pid, sts = os.waitpid(self.pid, flag)
  File "/home/pi/dyode_in/modbus.py", line 108, in modbus_loop
KeyboardInterrupt
    modbus_send_serial(data, properties)
  File "/home/pi/dyode_in/modbus.py", line 100, in modbus_send_serial
Error in sys.exitfunc:
Traceback (most recent call last):
  File "/usr/lib/python2.7/atexit.py", line 24, in _run_exitfuncs
    ser.write(encoded_data)
    func(*targs, **kargs)
  File "/usr/lib/python2.7/multiprocessing/util.py", line 325, in _exit_function
  File "/usr/lib/python2.7/dist-packages/serial/serialposix.py", line 542, in write
    p.join()
  File "/usr/lib/python2.7/multiprocessing/process.py", line 145, in join
    res = self._popen.wait(timeout)
  File "/usr/lib/python2.7/multiprocessing/forking.py", line 154, in wait
    return self.poll(0)
  File "/usr/lib/python2.7/multiprocessing/forking.py", line 135, in poll
    pid, sts = os.waitpid(self.pid, flag)
KeyboardInterrupt
    abort, ready, _ = select.select([self.pipe_abort_write_r], [self.fd], [], None)
KeyboardInterrupt

raspifuzzy, 2017-12-28:
Remaks:
Maybe I'm wrong but according to the Datasheet, I think there is a mistake in the pinout's of the HCPL-7723-000E DIP-8

5 = GND
8 = + 3.3V
6 = Vout

arnaudsoullie, 2017-12-28:
From the error log it seems that your Input Rapsberry is not able to connect to the PLC:
``ERROR:pymodbus.client.sync:Connection to (192.168.78.50, 502) failed: [Errno 111] Connection refused``

What kind of device is 192.168.78.50 ? Is a modbus slave running on port 502 ? You can use ``mbtget`` to test your Modbus slave prior to implementing DYODE.

arnaudsoullie, 2017-12-28:
Regarding the pinout, it is not very clear in the Wiki, but when I mention ``3.3V -> 3`` for the input Raspi, I mean the PIN 3 on the pin header, not on the optocoupler.
This is a bit confusing I have to admit.

raspifuzzy, 2017-12-28:
Device is a RaspPi3. I only install the latest Raspian Version, and then installed your setup step by step.
I had to admit that I have no experience with python or programming in general.

mbtget gives me following message:

server connect [localhost]:502 failed

arnaudsoullie, 2017-12-28:
OK.
You should have:
[Modbus device (slave)]<-->[input raspi]-->optocoupler-->[output raspi]<-->[Modbus device (master)]
At the moment it seems that you do not have a Modbus slave working since you're not able to query it using ``mbtget``

What is the modbus device you're trying to get data from ?

raspifuzzy, 2017-12-28:
Well actually I have both Raspberry's connected on the same router (Fritzbox) via LAN.
[Router] <--> Raspi 192.168.78.50 --> optocoupler --> Raspi 192.168.78.49 <--> [Router]

When typing "sudo python dyode_out.py" on the output raspi it gives me until pressing "^C":

INFO:root:Loading config file
INFO:root:Configuration name : Dyode v2
INFO:root:Configuration version : 1.0
INFO:root:Configuration date : 2017-07-25
DEBUG:root:Parsing "Automate Modbus 1"
DEBUG:root:Trying to launch a new process for module "Automate Modbus 1"
DEBUG:root:Modbus agent : Automate Modbus 1
DEBUG:root:Modbus master module : Automate Modbus 1
INFO:pymodbus.server.async:Starting Modbus TCP Server on 0.0.0.0:502
DEBUG:root:Updating : Automate Modbus 1
DEBUG:root:{'coils': ['0-1'], 'registers': ['9-105'], 'port_out': 502, 'ip': '192.168.78.50', 'type': 'modbus', 'port': 9400}
DEBUG:root:['9-105']
ERROR:root:Error obtaining Modbus values
ERROR:root:'NoneType' object has no attribute '__getitem__'
DEBUG:root:Updating : Automate Modbus 1
DEBUG:root:{'coils': ['0-1'], 'registers': ['9-105'], 'port_out': 502, 'ip': '192.168.78.50', 'type': 'modbus', 'port': 9400}
DEBUG:root:['9-105']
ERROR:root:Error obtaining Modbus values
ERROR:root:'NoneType' object has no attribute '__getitem__'
DEBUG:root:Updating : Automate Modbus 1
DEBUG:root:{'coils': ['0-1'], 'registers': ['9-105'], 'port_out': 502, 'ip': '192.168.78.50', 'type': 'modbus', 'port': 9400}
DEBUG:root:['9-105']

arnaudsoullie, 2017-12-28:
Well I can only suggest to take a look at the  [presentations of this project](https://github.com/wavestone-cdt/dyode/tree/master/Talks) in order for you to understand the use cases.

1. Two Raspberry Pis are needed for DYODE, but you also need Modbus devices that will use DYODE as a data diode. DYODE itself is useless if you have no data to transmit, which seems to be your case. You need to modify the config file to define what is the modbus device from which to get data.
If you do not have any additional Modbus device, then install a modbus simulator on the INPUT Raspi and set 127.0.0.1 as the ip of the plc.
You get ``ERROR:root:Error obtaining Modbus values`` on the output because you have ``ERROR:pymodbus.client.sync:Connection to (192.168.78.50, 502) failed: [Errno 111] Connection refused`` on the input
2. While it is acceptable for testing, please note that it does not make any sense to connect both Raspberry Pis to the same router, as it will allow the data diode to be trivially bypassed.

raspifuzzy, 2017-12-28:
Thanks a lot. I see more clear now, and will try your suggestion in new year cause hollydays now.
Bonne fin d‘année et joyeuses fêtes!

arnaudsoullie, 2019-10-20:
I just realized I never closed this issue, doing it now

Closed 2019-10-20.

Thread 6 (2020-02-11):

3d file for the editing

lcheng62, 2020-02-11:
Hi,

Do you still have the scad file(or equivalent file) that I can make the edit on the v2 case hardware?

Thanks,

arnaudsoullie, 2021-04-16:
Waouh. Sorry for the very delayed answer..
Here's the link to the case on TinkerCAD: https://www.tinkercad.com/things/6vvMWsDaUBd

In addition, I attached the .STL and .OBJ files
[DYODE-Pi0-case bottomv1.zip](https://github.com/wavestone-cdt/dyode/files/6327041/DYODE-Pi0-case.bottomv1.zip)
[DYODE-Pi0-case bottomv1.zip](https://github.com/wavestone-cdt/dyode/files/6327042/DYODE-Pi0-case.bottomv1.zip)

Closed 2021-04-16.

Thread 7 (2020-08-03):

DIP switch Status

biswaKL, 2020-08-03:
Can you please share your status which you set the for the DIP switches.
I guess its not working for normal ones (without DIP)

adamliq, 2021-01-23:
Biswakl did you get any further with this. As its not working for my tp-link media convertor with no dip switch.

biswaKL, 2021-01-23:
nope.. it was a dead end.

ajs-88, 2021-09-02:
@biswaKL have you tested any media converter with DIP switch? can you share model information?

biswaKL, 2021-09-02:
@ajs-88 it was a dead end for me.

Closed 2021-09-02.

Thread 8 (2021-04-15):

Media Converters

therion667, 2021-04-15:
Guys,
I have been trying to set your DYODE up. software setup seems fine and running but my converters Ultimode M-023M doesn not want to establish a correct link.
When I connect Tx to Rx and Tx to Rx the files are received but when I disconnect Tx cable from receiver converter and connect it to another converter to Tx socket the flow stops. Maybe the dead end converter needs to have some specific function?
Are there any specific parameters of TpLinks that you've used? I can try to buy and use the ones that you've used if neccecery.

Thanks in advance!

arnaudsoullie, 2021-04-16:
Hi!

This behavior might indeed be linked to the specifics of the Copper/Optical converters. I can only confirm that I did not do anything special to the ones I used. I used TP-LINK MC100CM.

therion667, 2021-04-16:
I came up with idea that maybe the addresses are wrong like in [here](https://github.com/wavestone-cdt/dyode/issues/3). Basing on [this](https://www.udpcast.linux.lu/satellite.html) line 100 in dyode.py has two same addresses which should be different? I will take a look at this next week and mingle with udpcast. If this won't work I will buy those converters. Please dont close I will try to post something afterwards.

therion667, 2021-04-27:
Ok so seems like on wireshark I'm getting only ARP done by eth0 on OUT part. Anything special about IP configuration on the diodes? I just set IP 10.0.1.1/24 and that's it.

arnaudsoullie, 2021-04-28:
You need to make sure that you set up MAC addresses correctly in the configuration file :
`dyode_in:
  ip: 10.0.1.1
  mac: b8:27:eb:89:1e:f3
dyode_out:
  ip: 10.0.1.2
  mac: b8:27:eb:b1:ff:ab`

Since there is no bidirectionnal comms, ARP requests do not go through.

Have you defined the right info in the config file on each side?

therion667, 2021-04-28:
Sure, the config is done correctly.
I've decided to set static MACs with IPs in /etc/ethers on both sides and well the data started to flow. No more ARP packets on wireshark.
I've also managed to send something using netcat. But udpcast seems to fail. When I use clear command copied from your code I get strange outcomes:
1. Waiting for file is long. IN Pi is actually sending 6 bit file every 3 seconds. For OUT to see the file takes really long time.
2. When using the command I can see transfer but no file. Under -f flag I just paste the /home/pi/in dir.
When I use your code I get this:
1. Nothing is showing up and the udp-receive command has 'Manifest folder 1.cfg' after -f flag. Is that correct?
2. Even after long time sometimes the manifest file comes through and file with HSD48FDSA is being created empty. Sometimes the manifest file contains the contents of the file that I've sent or [FILE] and directory plus hash but nothing else happens after that.

Sorry for expanding the issue for so long. Maybe some settings changed with newer Raspbian releases.

aruljane, 2021-08-30:
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

Hi @arnaudsoullie kindly elaborate on this point "MAC addresses need of course to be the ones of your Ethernet/Optical converters". Currently I have configured dyode_in 10.1.1.1 & raspberry pi eth0 Mac address and dyode_out 10.1.1.2 & raspberry pi eth0 Mac address and its not working. I verified ARP table on both ends and they are correct. But its not working. IM using MC200CM TPLINK. From your point how can I extract MAC address of Ethernet / Optical converters? Its a Layer 1 device right? Kindly advise.

ajs-88, 2021-08-30:
@arnaudsoullie Is there any limitations to keep in mind when choosing a copper to fiber media converter?

therion667, 2021-08-30:
I've fixed the issues.
Seemed like the highside mediaconverter needed to be with DIP switch and not the rest. I might test on other models in the future.
Right now I am working on the speed. For now I can get as high as 100 mb a 1 minute which for my use is not that bad. I might be fooling around with UDP cast settings. With more speed the stability drops and lowside dyode gets error on hashing the incoming file (it finished downloading even that the file is still flowing). Less speed = more stability.

ajs-88, 2021-08-30:
@therion667 great work! Kindly suggest me which media converter you tested? Model and specifications

ajs-88, 2021-09-02:
@therion667 Kindly advise which model worked for you?

ajs-88, 2021-09-04:
@therion667 I kindly request you to share the model details you have successfully tested.

therion667, 2021-09-04:
@ajs-88 sure,
so it was tested on mentioned:
Ultimode M-023M
TP-LINK MC100CM without DIP switch
Allied Telesis MC102XL

it worked only on TP-LINK MC100CM with DIp switch with Auto Negotiation OFF

Vrolijk, 2022-02-01:
Hi,

Have you seen the 2 optic-copper solution from klockcykel?
https://github.com/klockcykel/godiode

For their project they used 2 TP-Link MC200CM gigabit optic-copper converters with a small hardware mod. Could be a nice extra option for your great project.

Regards,
René

arnaudsoullie, 2022-02-01:
That's interesting thank you!

Closed 2023-09-04.

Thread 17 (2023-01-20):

[question] Switching ports "up" and "down"

ryneeverett, 2023-01-20:
In your slides you say about "cutting the cable":

> In theory, advanced attacks may allow to send information the other way around, for example by switching ports “up” and “down”

Could you elaborate on this? Are you referring to [Auto MDI-X](https://en.wikipedia.org/wiki/Medium-dependent_interface#Auto_MDI-X)? Are you aware of any research on this?

Thanks,

arnaudsoullie, 2024-01-04:
It was a long time ago and I do not remember...
Yes, auto MDI-X might perhaps be abused for that.

I would need to dive into Ethernet linkup process rabbit hole to answer correctly; my take today is that with proper configuration of the Ethernet interfaces it might not be so easily possible.

Closed 2024-01-04.

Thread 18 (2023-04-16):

What is the point of capacitors ?

IArchi, 2023-04-16:
Hello,

Could you let me know why you need 0.1uF capacitors around the optocoupler ?
Is it to smooth the input voltage ?

Thanks for your time

arnaudsoullie, 2023-09-04:
I do not really know,  I just followed the datasheet instructions :)
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

netcarver, 2023-09-04:
@IArchi Take a look at the [bypass/decoupling capacitor article on wikipedia](https://en.wikipedia.org/wiki/Decoupling_capacitor) for more info. Here's a small section, but it's not limited to this - though it is the way I tend to think about them.

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

Closed 2023-09-04.

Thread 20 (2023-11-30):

HCPL-7723 requires 5V voltage

IArchi, 2023-11-30:
Hey there,

Thanks for your code. I'm trying to recreate your DYIODE light box but I can't make the HCPL works correctly.
Apparently, it requires 5V input (4.5 to 5.5V) but you power it with the 3.3V pi GPIO.
If I try to do the same thing, the optocoupler does not work and no signal is received.

Do I need to power it by 5V and add a voltage divider to get 3.3V on RX ?

arnaudsoullie, 2024-01-04:
Hello,
According to the picture I posted and the pinout of the v1.3 Raspi Zero, you are right, I'm powering it from the 3.3V, not the 5V.
Unfortunately this is an old project and I cannot find this exact prototype anymore.
I found another version using Raspberry Pi 2B v1.2 (at some point it was not possible to find Raspi Zero without WiFi, and that would introduce an obvious side-channel attack possibility), and it is also using the 3.3V power pin...

So, I guess you are right but it did work for me at some point ¯\_(ツ)_/¯

Closed 2024-01-04.

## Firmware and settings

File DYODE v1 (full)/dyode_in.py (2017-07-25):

# -*- coding: utf-8 -*-
import dyode
import time
import sys
import yaml
import pyinotify
import logging
from math import floor
import subprocess
import multiprocessing
import shlex
import asyncore
import modbus
import os
import screen

# Max bitrate, empirical, should be a bit less than 100 but isn't
MAX_BITRATE = 8

# Logging
logging.basicConfig()
log = logging.getLogger()
log.setLevel(logging.DEBUG)

class EventHandler(pyinotify.ProcessEvent):
    def process_IN_CLOSE_WRITE(self, event):
        log.info('New file detected :: %s' % event.pathname)
        # If a new file is detected, launch the copy
        dyode.file_copy(multiprocessing.current_process()._args)

# When a new file finished copying in the input folder, send it
def watch_folder(properties):
    log.debug('Function "folder" launched with params %s: ' % properties)

    # inotify kernel watchdog stuff
    wm = pyinotify.WatchManager()
    mask = pyinotify.IN_CLOSE_WRITE
    notifier = pyinotify.AsyncNotifier(wm, EventHandler())
    wdd = wm.add_watch(properties['in'], mask, rec = True)
    log.debug('watching :: %s' % properties['in'])
    asyncore.loop()


def launch_agents(module, properties):
    log.debug(module)
    properties['bitrate'] = bitrate
    log.debug(properties)
    if properties['type'] == 'folder':
        log.debug('Instanciating a file transfer module :: %s' % module)
        watch_folder(properties)
    elif properties['type'] == 'modbus':
        log.debug('Modbus agent : %s' % module)
        modbus.modbus_loop(module, properties)
    elif properties['type'] == 'screen':
        log.debug('Screen sharing agent : %s' % module)
        screen.watch_folder(module, properties)


if __name__ == '__main__':
    with open('config.yaml', 'r') as config_file:
        config = yaml.load(config_file)

    # Log infos about the configuration file
    log.info('Loading config file')
    log.info('Configuration name : %s' % config['config_name'])
    log.info('Configuration version : %s' % config['config_version'])
    log.info('Configuration date : %s' % config['config_date'])

    # Static ARP
    log.info('Dyode input ip : %s (%s)' % (config['dyode_in']['ip'], config['dyode_in']['mac']))
    log.info('Dyode output ip : %s (%s)' % (config['dyode_out']['ip'], config['dyode_out']['mac']))
    p = subprocess.Popen(shlex.split('arp -s ' + config['dyode_out']['ip'] + ' ' + config['dyode_out']['mac']), shell=False, stdout=subprocess.PIPE, stderr=subprocess.PIPE)
    output, err = p.communicate()

    # Number of modules (needed to calculate bitrate)
    # Only works for file transfer using udpcast
    # TODO : Screen sharing needs more bandwidth
    # TODO : Needs to be updated for socket transfer
    modules_nb = len((config['modules']))
    log.debug('Number of modules : %s' % len(config['modules']))
    bitrate = floor(MAX_BITRATE / modules_nb)
    log.debug('Max bitrate per module : %s mbps' % bitrate)

    # Iterate on modules
    modules = config.get('modules')
    for module, properties in modules.iteritems():
        log.debug('Parsing %s' % module)
        log.debug('Trying to launch a new process for module %s' % module)
        p = multiprocessing.Process(name=str(module), target=launch_agents, args=(module, properties))
        p.start()

    # TODO : Check if all modules are still alive and restart the ones that are not

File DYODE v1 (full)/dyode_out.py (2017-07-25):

# -*- coding: utf-8 -*-
import dyode
import time
import os
import sys
import yaml
import pyinotify
import modbus
import screen
import logging
import shlex
from math import floor
import multiprocessing
import asyncore

# Max bitrate, empirical, should be a bit less than 100 but isn't
MAX_BITRATE = 20

# Logging
logging.basicConfig()
log = logging.getLogger()
log.setLevel(logging.DEBUG)


def launch_agents(module, properties):
    if properties['type'] == 'folder':
        log.debug('Instanciating a file transfer module :: %s' % module)
        dyode.file_reception_loop(properties)
    elif properties['type'] == 'modbus':
        log.debug('Modbus agent : %s' % module)
        modbus.modbus_master(module, properties)
    elif properties['type'] == 'screen':
        log.debug('Screen sharing : %s' % module)
        screen_process = multiprocessing.Process(name='http_server', target=screen.http_server, args=(module, properties))
        screen_process.start()


if __name__ == '__main__':
    with open('config.yaml', 'r') as config_file:
        config = yaml.load(config_file)

    # Log infos about the configuration file
    log.info('Loading config file')
    log.info('Configuration name : ' + config['config_name'])
    log.info('Configuration version : ' + str(config['config_version']))
    log.info('Configuration date : ' + str(config['config_date']))

    # Static ARP
    log.info('Dyode input ip : ' + str(config['dyode_in']['ip']) + ' (' + str(config['dyode_in']['mac']) + ')' )
    log.info('Dyode output ip : ' + str(config['dyode_out']['ip']) + ' (' + str(config['dyode_out']['mac']) + ')' )

    # Iterate on modules
    modules = config.get('modules')
    for module, properties in modules.iteritems():
        #print module
        log.debug('Parsing "' + module + '"')
        log.debug('Trying to launch a new process for module "' + str(module) +'"')
        p = multiprocessing.Process(name=str(module), target=launch_agents, args=(module, properties))
        p.start()

    # TODO : Check if all modules are still alive and restart the ones that are not
